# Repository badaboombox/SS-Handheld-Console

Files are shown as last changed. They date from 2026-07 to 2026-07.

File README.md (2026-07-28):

# SS Handheld Console

An open-source handheld game console built around an FPGA graphics engine. It runs
DS-era style 2D and 3D games at a steady 60 fps.

SS stands for Single Screen: a single-screen take on the dual-screen handheld era.

Most open-source consoles are 2D only, or run 3D in software that can't hold a
frame rate. This one does perspective-correct textured 3D and a GBA-class 2D
tile/sprite engine together on one FPGA, composited to a 480x272 panel
at 60 Hz. The whole bitstream builds with an open toolchain (Yosys, nextpnr,
Project Trellis), so no proprietary EDA is needed.

<p align="center">
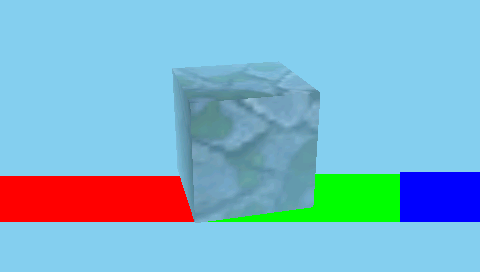
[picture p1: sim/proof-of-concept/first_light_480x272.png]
Textured, lit, fogged 3D from RTL sim
  
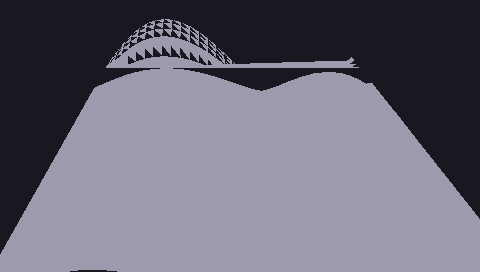
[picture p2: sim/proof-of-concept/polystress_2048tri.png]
2048-triangle stress scene at about 100 fps
  
</p>
<p align="center">
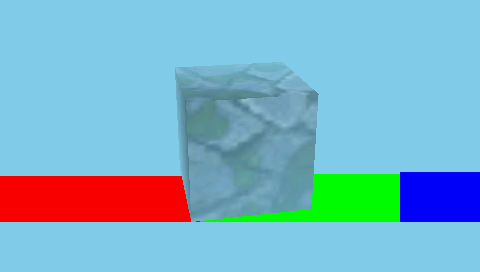
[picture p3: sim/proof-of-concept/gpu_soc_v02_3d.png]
Full SoC 3D render
  
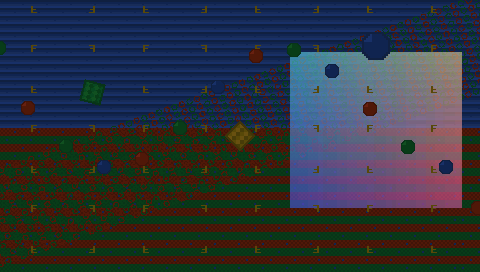
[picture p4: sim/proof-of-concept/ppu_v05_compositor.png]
Layered 2D with compositor
  
</p>

> These frames come straight out of the Verilog RTL in simulation. There are more
> in [sim/proof-of-concept/](sim/proof-of-concept/).

## What it is

Two chips split the work.

The Lattice ECP5 (LFE5U-85F) runs the graphics engine: a 2D tile and sprite PPU
(text and affine backgrounds, sprites, a scanline compositor), a perspective-correct
textured 3D rasterizer, a 32-bit SDRAM subsystem, and RGB panel scanout. All of it
is custom Verilog.

The STM32H723 runs game logic, audio, input, and 3D geometry, streaming
screen-space work to the FPGA over a parallel bus.

The 3D core is built on [RasterIX](https://github.com/ToNi3141/RasterIX) (see
[Credits](#credits)) and extended into a gaming-oriented hybrid GPU that sits next
to the 2D engine and compositor.

## Where it stands

Everything below is validated in simulation and synthesis.

- It fits the LFE5U-85F (caBGA-381) with room to spare: about 34% logic, 72% block
  RAM, 80% DSP.
- Both clock domains meet timing. The GPU domain runs at 73.5 MHz against a 66.67
  target, and the SDRAM domain at 174 MHz against a 133 target. The build is pinned
  to a deterministic place-and-route seed.
- The full pipeline is pixel-exact in simulation. The frames above are direct
  Verilator renders, including a 2048-triangle stress scene at roughly 100 fps.

## Repository layout

| Path | Contents |
|---|---|
| [rtl/](rtl/) | All the Verilog: 2D PPU, 3D integration, SDRAM controller and clock crossing, FMC bridge, scanout, clocking, board top. |
| [hardware/](hardware/) | KiCad project for the 6-layer board: ECP5, STM32H723, SDRAM, panel, power, audio, controls. |
| [build/](build/) | Bitstream build notes and the reproduce recipe. |
| [sim/](sim/) | Verilator testbenches for every RTL block plus a headless 3D harness. Rendered frames are in sim/proof-of-concept/. |

## Building the bitstream

No vendor tools:

```sh
yosys <synth script>            # produces gpuchip_ecp5.json
nextpnr-ecp5 --85k --package CABGA381 --speed 8 \
  --json gpuchip_ecp5.json --lpf rtl/gpu_chip.lpf --seed 4 \
  --textcfg gpuchip.config
ecppack gpuchip.config gpuchip.bit
```

The RTL depends on the RasterIX 3D core, included here as a submodule. Clone with
submodules so it comes along:

```sh
git clone --recursive <repo-url>
# or, in an existing clone:
git submodule update --init --recursive
```

The full recipe and flashing steps are in [build/README.md](build/README.md).

## Hardware

<p align="center">
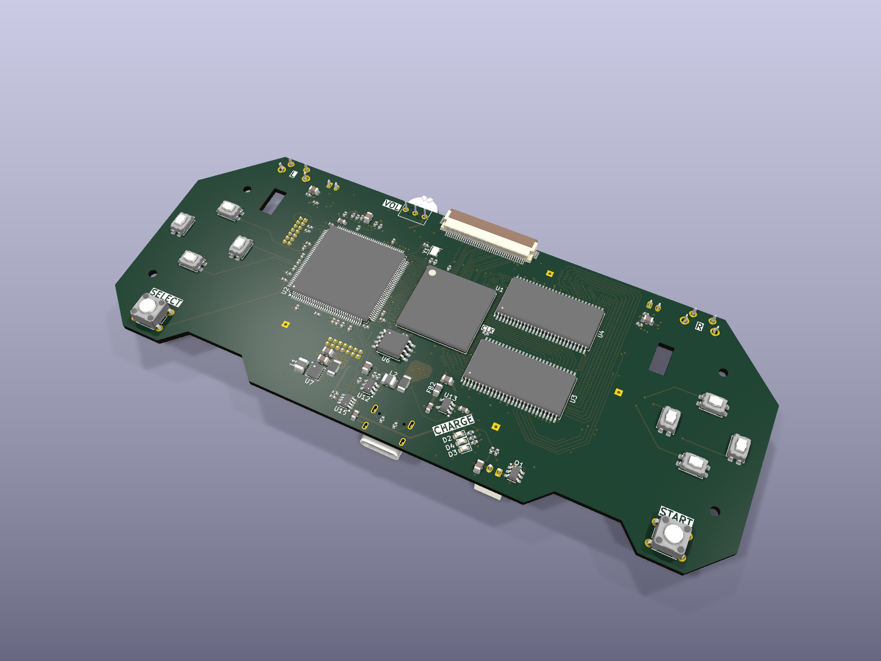
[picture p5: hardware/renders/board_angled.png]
3D render of the SS Handheld Console mainboard
  
</p>

A 6-layer board in KiCad: the ECP5-85 FPGA and STM32H723 MCU, 32-bit SDRAM, a 4.3
inch 480x272 RGB panel with a boost-driven backlight, microSD, USB-C charging,
stereo audio, and tactile controls. Schematics, layout, and 3D renders are under
[hardware/](hardware/).

## Status

This is a bring-up prototype (v0.1). The design is validated in simulation and
synthesis. First hardware bring-up and a likely v0.2 respin are the next steps.

## Credits

The 3D rasterizer is built on [RasterIX](https://github.com/ToNi3141/RasterIX) by
ToNi3141, an open-source fixed-function OpenGL-ES rasterizer (GPL-3.0). This
project extends it into a hybrid 2D and 3D console GPU. Big thanks to that work.

## License

The repository is dual-licensed by directory:

- rtl/ is GPL-3.0-or-later. The gateware is a derivative of RasterIX (GPL-3.0), so
  it carries the same copyleft terms.
- hardware/ is CERN-OHL-P-2.0, a permissive open-hardware license. The board is an
  independent work.

See [LICENSING.md](LICENSING.md) for the breakdown and the per-file SPDX tags.

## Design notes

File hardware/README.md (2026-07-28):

# Hardware

The KiCad project for the SS Handheld Console board. It's a 6-layer PCB that
carries the FPGA, the MCU, memory, the display interface, power, audio amps, and
controls (basically everything).

## Renders

<p align="center">
  Angled 3D render of the mainboard
</p>
<p align="center">
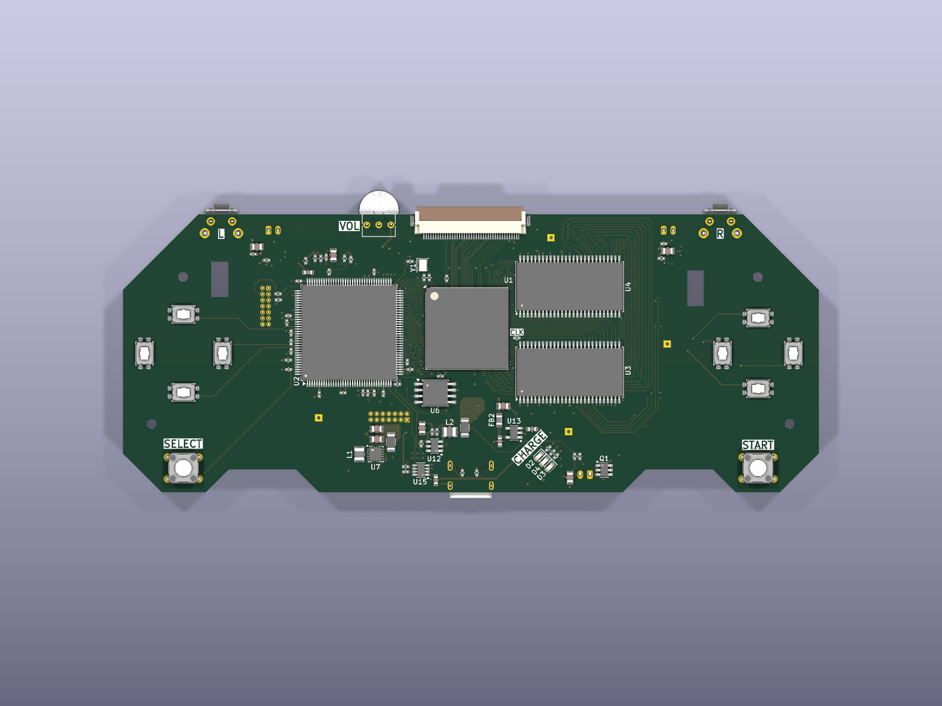
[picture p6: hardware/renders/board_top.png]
Top view
  
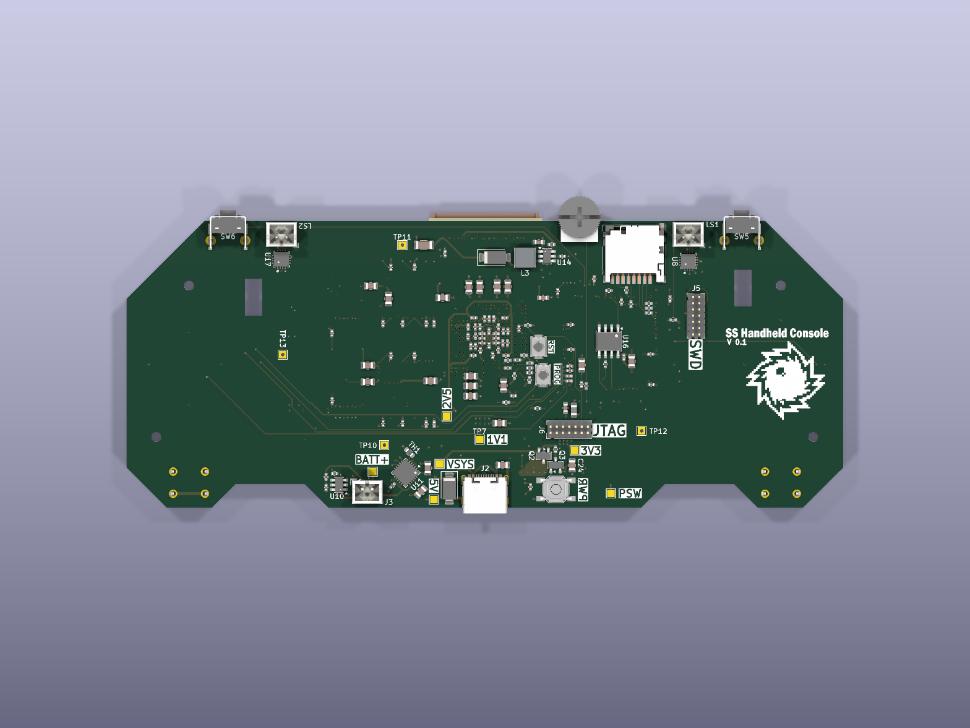
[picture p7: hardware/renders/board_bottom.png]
Bottom view
  
</p>

KiCad 3D renders of the current board (top, angled, and bottom).

## Main parts

- FPGA: Lattice ECP5 LFE5U-85F-8, caBGA-381, 0.8 mm pitch. Runs the main graphics engine.
- MCU: STM32H723, LQFP144. Game logic, audio, input, and some 3D geometry.
- Graphics memory: two 16-bit SDR SDRAM chips in parallel, for a 32-bit bus.
- Display: 4.3 inch 480x272 RGB (DPI) panel, with a boost-driven LED backlight.
- Storage: microSD, plus an SPI NOR flash that holds the FPGA configuration.
- MCU work RAM: QSPI PSRAM.
- Power: a single-cell 2500 mAh LiPo feeding a buck-boost 3.3 V rail, a 1.1 V core buck, a
  2.5 V aux LDO, and USB-C charging.
- Audio: stereo I2S class-D amplifiers.
- Controls: tactile D-pad, face, shoulder, and system buttons.

## Board

6-layer stackup: signal, ground, signal, ground, power, signal. The inner signal
layer sits between the two ground planes and mainly carries the SDRAM and FMC buses. The board uses
an ENIG finish for the fine-pitch BGA.

## Files

`Comp Board/` is the KiCad project: schematics, PCB, and the footprint and
3D-model libraries. Open `Comp Board/Comp Board.kicad_pro` in KiCad.

Exported for quick viewing without KiCad:

- [schematics.pdf](schematics.pdf) - all sheets.
- [board_layout.pdf](board_layout.pdf) - all six copper layers, one per page.
- [BOM.csv](BOM.csv) - grouped bill of materials (76 line items).

## License

The hardware is licensed under CERN-OHL-P-2.0 (see the LICENSE file in this
directory). The RTL under `rtl/` is licensed separately, under GPL-3.0-or-later.

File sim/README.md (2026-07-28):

# Simulation

Verilator testbenches for each RTL block, plus a headless harness for the 3D core.
The frames these produce are in [proof-of-concept/](proof-of-concept/).

| Directory | What it tests |
|---|---|
| ppu/ | 2D PPU: tile and affine backgrounds, sprites, compositor. Renders a frame to `ppu_frame.ppm`. |
| ppu_sdram/ | The PPU running over the real SDRAM controller and cache. |
| gpu/ | The full graphics SoC top (PPU, 3D, SDRAM, FMC bridge). |
| sdram/ | The SDR SDRAM controller: init, refresh, burst-8. |
| fmc/ | The STM32 FMC parallel-bus bridge. |
| scanout/ | The DPI/RGB panel timing generator. |
| headless/ | The 3D core harness (CMake). Needs the RasterIX submodule. |

Each Verilator directory builds and runs with `make`. The headless harness uses
CMake and needs `external/RasterIX` (see the top-level README for the submodule
command).

Requirements: Verilator 5.x, and for the headless harness, CMake plus the RasterIX
submodule.

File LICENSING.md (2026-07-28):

# Licensing

This project is dual-licensed by directory, because the gateware and the hardware
have different origins and obligations.

## rtl/ is GPL-3.0-or-later

The RTL is a derivative work of [RasterIX](https://github.com/ToNi3141/RasterIX),
which is licensed GPL-3.0. Strong copyleft propagates: any distributed work that
incorporates GPL-3.0 code must itself be GPL-3.0-compatible. So all the Verilog
under rtl/ is licensed GPL-3.0-or-later. The full text is in [LICENSE](LICENSE).

`SPDX-License-Identifier: GPL-3.0-or-later`

## hardware/ is CERN-OHL-P-2.0

The PCB and KiCad design under hardware/ is an independent work. It hosts the FPGA;
it is not a derivative of the GPL RTL. It is licensed under the CERN Open Hardware
Licence Version 2, Permissive (CERN-OHL-P-2.0), so the board can be used, modified,
and manufactured freely. The full text is in [hardware/LICENSE](hardware/LICENSE).

`SPDX-License-Identifier: CERN-OHL-P-2.0`

## Media

Render frames and documentation images (sim/proof-of-concept/ and the README
images) are licensed CC-BY-4.0.

`SPDX-License-Identifier: CC-BY-4.0`

## Third party

RasterIX (external/RasterIX, pulled in as a submodule) is copyright ToNi3141 and
licensed GPL-3.0. It is not redistributed in this repository. See its own
repository for its license and terms.

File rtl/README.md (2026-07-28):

# RTL

All the Verilog for the SS Handheld graphics engine. It targets a Lattice
ECP5 (LFE5U-85F) and builds with Yosys and nextpnr.

## Top level

- `gpu_chip.v` is the board and synthesis top. It wraps the SoC, brings out the
  real chip pins (SDRAM, FMC, panel, clock, reset), sets up the PLL, and forwards
  the SDRAM clock through an ODDR. This is what gets synthesized into a bitstream.
- `gpu_top.v` is the SoC. It ties together the 2D PPU, the 3D core, the SDRAM
  subsystem, and the FMC bridge, along with the SDRAM arbitration and the
  framebuffer swap logic.
- `gpu_chip.lpf` holds the pin constraints (ball assignments and IO standards) for
  the CABGA381 package.
- `clkgen.v` sets up the ECP5 PLL: one 50 MHz reference in, a 66.67 MHz GPU clock
  and a 133.33 MHz SDRAM clock out.

## Blocks

| Path | What it does |
|---|---|
| ppu/ | 2D tile and sprite PPU: text and affine backgrounds, sprites, a shared cache and arbiter, and a scanline compositor. See [ppu/PPU_Microarch.md](ppu/PPU_Microarch.md). |
| sdram/ | 32-bit SDR SDRAM controller (init, refresh, burst-8), an AXI bridge, and the clock crossing that puts the controller in its own 133 MHz domain. |
| fmc/ | The STM32 FMC parallel-bus slave and the register file it drives. |
| scanout/ | DPI/RGB panel timing generator (480x272, sync and DE, RGB888 out). |

The 3D rasterizer is RasterIX, pulled in as a submodule at `external/RasterIX`, so
it is not part of this directory. `gpu_top` instantiates it.

## Clock domains

- GPU domain (66.67 MHz): the PPU, the 3D core, compositing, and scanout.
- SDRAM domain (133.33 MHz, exactly twice the GPU clock): the SDRAM controller,
  reached from the GPU domain through async FIFOs.

## Building

See the top-level README and [../build/README.md](../build/README.md). In short,
Yosys synthesizes `gpu_chip`, nextpnr places and routes it against `gpu_chip.lpf`,
and ecppack makes the bitstream. The build is pinned to a place-and-route seed so
timing is repeatable.

## Style

The RTL is written to synthesize cleanly with Yosys: Verilog-2005, memories as
plain arrays, no empty for-loop increments, and simulation-only asserts guarded by
`ifdef SIMULATION`.

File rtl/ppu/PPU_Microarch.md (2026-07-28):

# 2D PPU (Pixel Processing Unit) microarchitecture

The PPU renders one scanline at a time into a line buffer, which the scanout block
then streams to the panel. It draws four background layers (text or affine) and
sprites, composites them by priority with alpha blending, and can mix in the 3D
color buffer as another layer.

## Pipeline

All the renderers run concurrently for a given line. They share a single memory
port through a fixed-priority arbiter and a shared cache, so the per-line cost is
bounded by memory instead of the number of layers.

- The background renderers (text and affine) each produce one layer's pixels for
  the line.
- The sprite renderer scans the OAM for sprites on this line and plots them into
  a sprite line buffer.
- The 3D fetch unit reads the 3D color buffer for the line. It bypasses the cache,
  since that buffer is written once per frame and would only take up cache space.
- The compositor resolves all the sources by priority, applies alpha blending and
  brightness, and writes the final RGB565 pixel.

At 66.67 MHz the worst-case scene renders in about 35 microseconds per line, inside
the roughly 56 microsecond line budget. The shared cache runs around an 83% hit
rate on that scene.

## Backgrounds

- Text layers: 64x64 tilemaps of 8x8 4bpp tiles, 16 palettes, fine x and y scroll,
  horizontal and vertical flip.
- Affine layers: layers 2 and 3 can switch to affine mode. A DDA walks an s8.8
  matrix across a 512x512 wrapping world, with small map and tile caches.

## Sprites

- 256-entry OAM, preloaded over a write port.
- A per-line scan collects up to 64 sprites on the line.
- Square sizes from 8 to 64, 1D tile mapping, horizontal and vertical flip.
- X wraps in a 1024-wide space, so sprites clip cleanly off either edge.
- First writer wins per pixel, in OAM order, and a sprite beats a background at
  equal priority.
- Affine sprites use a 32-entry matrix table and GBA-style inverse mapping, with an
  optional double-size window.

## Compositor

- Per-pixel priority resolve across the four backgrounds, the sprite layer, and the
  3D layer.
- Alpha blending with a global eva and evb pair (in sixteenths) and a per-source
  enable.
- Brightness fade.
- The 3D color buffer is treated as a priority-assignable layer, so the compositor
  does not care about the ratio of 2D to 3D content.

## Formats

- Tilemap entry (16 bits): bits 9:0 tile index, bit 10 hflip, bit 11 vflip, bits
  15:12 palette.
- Tile: 8 rows of 32 bits, one 4bpp pixel per nibble, left pixel in the low nibble
  before flipping.
- Color 0 of each palette is transparent.
- Line-buffer color is RGB565.

## Files

| File | Role |
|---|---|
| ppu_top.v | Line sequencer and top level. |
| ppu_bg_line.v | Text background scanline renderer. |
| ppu_bg_affine_line.v | Affine background scanline renderer. |
| ppu_spr_line.v | Sprite scanline renderer: OAM scan, plotting, affine sprites. |
| ppu_arbiter.v | Fixed-priority memory arbiter. |
| ppu_cache.v | Shared direct-mapped read cache, flushed at frame start. |
| ppu_t3d_fetch.v | 3D color-buffer line fetch (bypasses the cache). |
| ppu_sdram_top.v | PPU wired to the SDRAM controller, for integration and sim. |

## Style

The RTL is Verilog-2005 and synthesizes cleanly with Yosys: memories are plain
arrays, there are no empty for-loop increments, and simulation asserts are guarded
by `ifdef SIMULATION`.

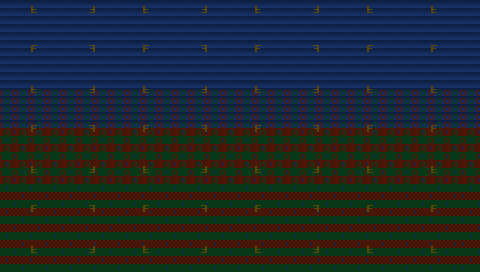
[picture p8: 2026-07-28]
sim/proof-of-concept/ppu_v02_4layers.png

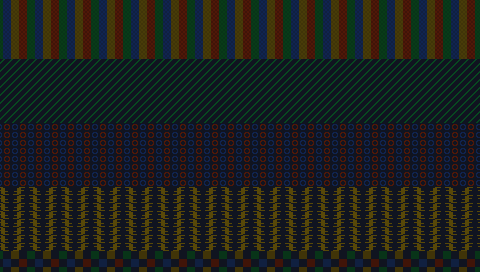
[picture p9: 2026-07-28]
sim/proof-of-concept/ppu_v01_first_frame.png

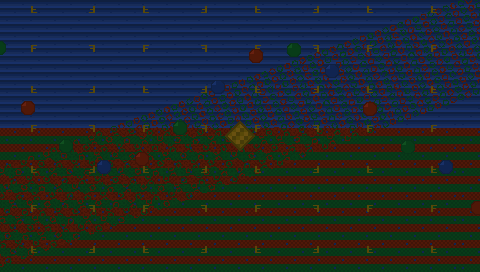
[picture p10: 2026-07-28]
sim/proof-of-concept/ppu_v04_affine.png

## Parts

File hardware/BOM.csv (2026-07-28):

Item | Designators | Value | Footprint | Qty | DNP
1 | C1,C3-C5,C19,C24,C27,C44,C51,C54,C61-C64,C88,C99,C103,C107,C111,C112,C119,C120,C130 | 10uF | Capacitor_SMD:C_0805_2012Metric | 23
2 | C2,C6-C18,C20,C31-C43,C45,C47,C52,C53,C55-C60,C65-C72,C74-C77,C85,C86,C89,C90,C92-C94,C96-C98,C100,C104,C105,C108,C110,C113-C118,C121-C126,C129,C131-C134 | 100nF | Capacitor_SMD:C_0402_1005Metric | 82
3 | C21,C28,C48 | 1uF | Capacitor_SMD:C_0603_1608Metric | 3
4 | C22 | 0.47uF | Capacitor_SMD:C_0402_1005Metric | 1
5 | C23 | 47nF | Capacitor_SMD:C_0402_1005Metric | 1
6 | C25,C26,C46,C87,C91,C95 | 22uF | Capacitor_SMD:C_0805_2012Metric | 6
7 | C29,C49,C50 | 2.2uF | Capacitor_SMD:C_0603_1608Metric | 3
8 | C30 | 4.7uF | Capacitor_SMD:C_0603_1608Metric | 1
9 | C127 | 1uF | Capacitor_SMD:C_1206_3216Metric | 1
10 | C128 | 220nF | Capacitor_SMD:C_0402_1005Metric | 1
11 | D1 | SMAJ5.0A | Diode_SMD:D_SMA | 1
12 | D2-D4 | LED | LED_SMD:LED_0603_1608Metric | 3
13 | D5 | SS16 | Diode_SMD:D_SMA | 1
14 | FB1 | 600@100MHz | Inductor_SMD:L_0805_2012Metric | 1
15 | FB2 | 120@100MHz | Inductor_SMD:L_0805_2012Metric | 1
16 | J1 | Micro_SD_Card_Det1 | Connector_Card:microSD_HC_Hirose_DM3D-SF | 1
17 | J2 | USB_C_Receptacle_USB2.0_16P | Connector_USB:USB_C_Receptacle_G-Switch_GT-USB-7010ASV | 1
18 | J3 | 1S LiPo | Connector_JST:JST_PH_B2B-PH-K_1x02_P2.00mm_Vertical | 1
19 | J4 | 0.5mm FPC Conn | Connector_FFC-FPC:Hirose_FH12-40S-0.5SH_1x40-1MP_P0.50mm_Horizontal | 1
20 | J5,J6 | Conn_ST_STDC14 | Connector_PinHeader_1.27mm:PinHeader_2x07_P1.27mm_Vertical | 2
21 | L1 | 1.5uH | Inductor_SMD:L_1008_2520Metric | 1
22 | L2 | 2.2uH | Inductor_SMD:L_1008_2520Metric | 1
23 | L3 | 10uH | Inductor_SMD:L_Abracon_ASPI-4030S | 1
24 | LS1,LS2 | Speaker 4-8 ohm | Connector_TE-Connectivity:TE_440054-2_1x02_P2.00mm_Vertical | 2
25 | Q1 | FS8205 | Package_TO_SOT_SMD:SOT-23-6 | 1
26 | Q2 | AO3401A | Package_TO_SOT_SMD:SOT-23 | 1
27 | Q3 | 2N7002 | Package_TO_SOT_SMD:SOT-23 | 1
28 | R1,R2 | 5.1k | Resistor_SMD:R_0402_1005Metric | 2
29 | R3,R8 | 2k | Resistor_SMD:R_0402_1005Metric | 2
30 | R4,R9,R41 | 1k | Resistor_SMD:R_0402_1005Metric | 3
31 | R5-R7 | 470 | Resistor_SMD:R_0402_1005Metric | 3
32 | R10,R45-R49 | 47k | Resistor_SMD:R_0402_1005Metric | 6
33 | R11-R13,R15,R53 | 100k | Resistor_SMD:R_0402_1005Metric | 5
34 | R14 | 120k | Resistor_SMD:R_0402_1005Metric | 1
35 | R16,R19-R22,R33-R36,R42,R43,R57 | 10k | Resistor_SMD:R_0402_1005Metric | 12
36 | R17,R18 | 49.9 | Resistor_SMD:R_0402_1005Metric | 2
37 | R23-R28,R44,R56 | 22 | Resistor_SMD:R_0402_1005Metric | 8
38 | R29,R38,R55 | 33 | Resistor_SMD:R_0402_1005Metric | 3
39 | R30-R32,R40 | 4.7k | Resistor_SMD:R_0402_1005Metric | 4
40 | R37 | 10 | Resistor_SMD:R_0402_1005Metric | 1
41 | R39 | 240k | Resistor_SMD:R_0402_1005Metric | 1
42 | R50,R51 | 0 | Resistor_SMD:R_1206_3216Metric | 2
43 | R54 | 220k | Resistor_SMD:R_0402_1005Metric | 1
44 | RV1 | 10k Linear | Potentiometer_THT:Potentiometer_Bourns_3266Y_Vertical | 1
45 | SW1 | D_UP | Button_Switch_SMD:SW_SPST_EVQP2_ShortPushTravel_H2.5mm | 1
46 | SW2 | D_DOWN | Button_Switch_SMD:SW_SPST_EVQP2_ShortPushTravel_H2.5mm | 1
47 | SW3 | D_LEFT | Button_Switch_SMD:SW_SPST_EVQP2_ShortPushTravel_H2.5mm | 1
48 | SW4 | D_RIGHT | Button_Switch_SMD:SW_SPST_EVQP2_ShortPushTravel_H2.5mm | 1
49 | SW5 | L | Button_Switch_THT:SW_Tactile_SPST_Angled_PTS645Vx39-2LFS | 1
50 | SW6 | R | Button_Switch_THT:SW_Tactile_SPST_Angled_PTS645Vx39-2LFS | 1
51 | SW7 | A | Button_Switch_SMD:SW_SPST_EVQP2_ShortPushTravel_H2.5mm | 1
52 | SW8 | B | Button_Switch_SMD:SW_SPST_EVQP2_ShortPushTravel_H2.5mm | 1
53 | SW9 | X | Button_Switch_SMD:SW_SPST_EVQP2_ShortPushTravel_H2.5mm | 1
54 | SW10 | Y | Button_Switch_SMD:SW_SPST_EVQP2_ShortPushTravel_H2.5mm | 1
55 | SW11 | START | Button_Switch_THT:SW_TH_Tactile_Omron_B3F-100x | 1
56 | SW12 | SEL | Button_Switch_THT:SW_TH_Tactile_Omron_B3F-100x | 1
57 | SW13 | MAIN | Button_Switch_SMD:SW_SPST_SKQG_WithStem | 1
58 | SW14 | FORCE_RECON | Button_Switch_SMD:SW_Push_SPST_NO_Alps_SKRK | 1
59 | SW15 | SW_Push | Button_Switch_SMD:SW_Push_SPST_NO_Alps_SKRK | 1
60 | TH1 | NTC 10k | Resistor_SMD:R_0603_1608Metric | 1
61 | TP1,TP3-TP5,TP7-TP9 | TestPoint | TestPoint:TestPoint_Pad_1.5x1.5mm | 7
62 | TP10-TP13 | TestPoint | TestPoint:TestPoint_THTPad_1.5x1.5mm_Drill0.7mm | 4
63 | U1 | LFE5U-85F-8BG381x | Package_BGA:Lattice_caBGA-381_17x17mm_Layout20x20_P0.8mm | 1
64 | U2 | STM32H723ZGTx | Package_QFP:LQFP-144_20x20mm_P0.5mm | 1
65 | U3,U4 | AS4C4M16SA | Package_SO:TSOP-II-54_22.2x10.16mm_P0.8mm | 2
66 | U6 | W25Q32JVSS | Package_SO:SOIC-8_5.3x5.3mm_P1.27mm | 1
67 | U7 | TPS63001 | Package_SON:Texas_DRC0010J_ThermalVias | 1
68 | U8,U17 | MAX98357A | Package_DFN_QFN:TQFN-16-1EP_3x3mm_P0.5mm_EP1.23x1.23mm | 2
69 | U10 | DW01A | Package_TO_SOT_SMD:SOT-23-6 | 1
70 | U11 | MCP73871 | Package_DFN_QFN:QFN-20-1EP_4x4mm_P0.5mm_EP2.5x2.5mm | 1
71 | U12 | TLV62569DDC | Package_TO_SOT_SMD:SOT-23-6 | 1
72 | U13 | AP2112K-2.5 | Package_TO_SOT_SMD:SOT-23-5 | 1
73 | U14 | TPS61165DBV | Package_TO_SOT_SMD:SOT-23-6 | 1
74 | U15 | LTC2954CTS8-1-TRPBF | Package_TO_SOT_SMD:TSOT-23-8 | 1
75 | U16 | APS6404L-3SQRx-SN | Package_SO:SOIC-8_3.9x4.9mm_P1.27mm | 1
76 | Y1 | SiT8008xx-7x-xxE | Oscillator:Oscillator_SMD_SiT_PQFN-4Pin_2.0x1.6mm | 1

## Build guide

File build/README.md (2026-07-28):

# Board-top bitstream

The ready-to-flash FPGA configuration for the board top (`gpu_chip`), built at a
pinned place-and-route seed. This is NOT a final build, so you should
rebuild it after any RTL change. A few things are still unfinished (command
response readback, NWAIT polarity, and real SDRAM pad timing).

The `.bit` and `.svf` binaries are git-ignored and regenerable. This README and the
verilog itself are tracked.

## Artifacts

- `gpuchip.bit` (about 2.3 MB): the SPI-flash image for the W25Q32 config flash,
  which the ECP5 boots from on power-up.
- `gpuchip.svf` (about 4.8 MB): a JTAG program file for a direct volatile load
  during bring-up.

## Provenance

- RTL: `rtl/gpu_chip.v` (the board top, with an ODDR-driven SDRAM clock), the rest
  of `rtl/`, and the RasterIX submodule.
- Pinout: `rtl/gpu_chip.lpf` (LFE5U-85F, CABGA381, 117 IO). nextpnr places all 117
  with no conflicts.
- Tools: Yosys, nextpnr-ecp5, and ecppack from Project Trellis.
- The build is pinned to a place-and-route seed because the GPU clock is
  seed-sensitive. The pinned seed gives clean margin and is deterministic.
- Post-route timing: GPU clock 73.46 MHz against a 66.67 target, SDRAM clock
  174.58 MHz against a 133.33 target, so both pass.

## Regenerate

```sh
yosys gpuchip.ys                 # creates gpuchip_ecp5.json
nextpnr-ecp5 --85k --package CABGA381 --speed 8 \
  --json gpuchip_ecp5.json --lpf ../rtl/gpu_chip.lpf --lpf-allow-unconstrained \
  --seed 4 --textcfg gpuchip.config
ecppack gpuchip.config gpuchip.bit         # SPI-flash image
ecppack --svf gpuchip.svf gpuchip.config   # JTAG
```

## Flashing at bring-up

- SPI flash: write `gpuchip.bit` to the W25Q32, for example with
  `openFPGALoader -c <cable> -f gpuchip.bit`, or through the config-flash header.
  The ECP5 boots it during power on, with the config straps set to Master SPI.
- JTAG bench load: `openFPGALoader -c <cable> gpuchip.svf` for a quick volatile
  load without touching flash.

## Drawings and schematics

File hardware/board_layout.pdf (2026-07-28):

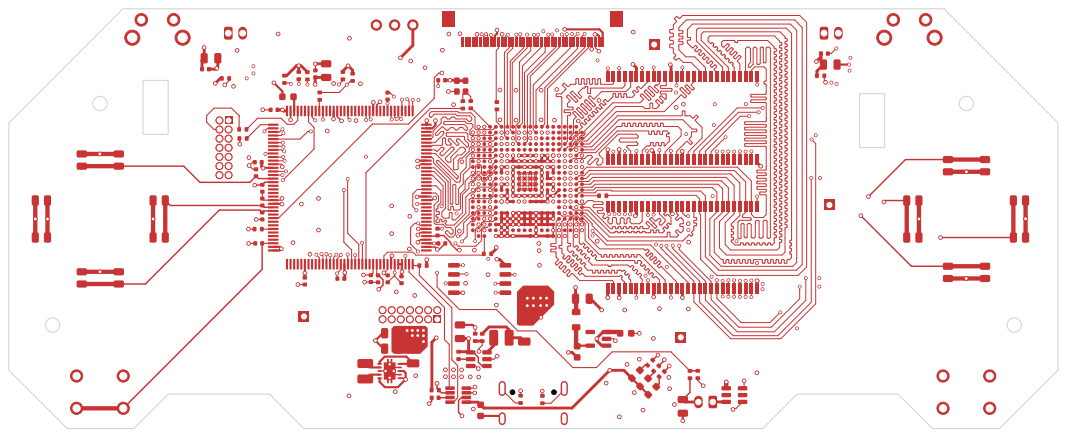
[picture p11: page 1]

Size: A4 | Rev:
KiCad E.D.A. 10.0.3 | Id: 1/6

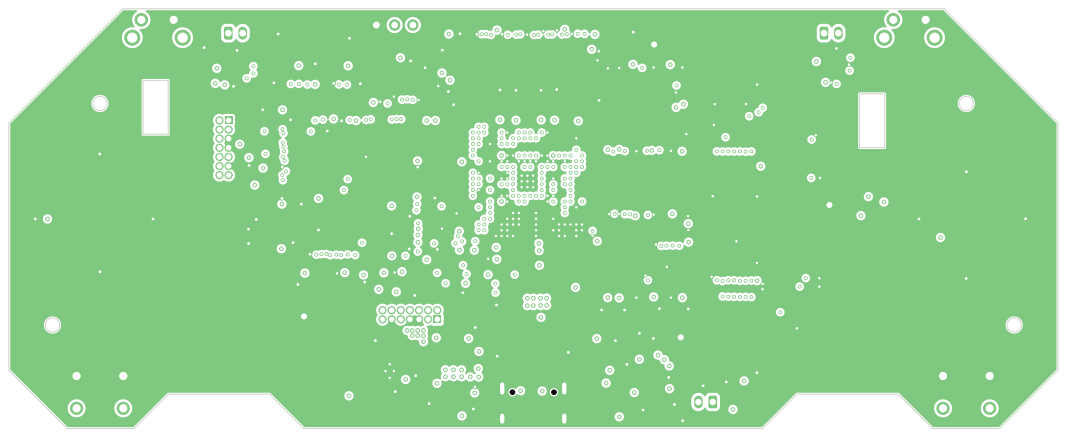
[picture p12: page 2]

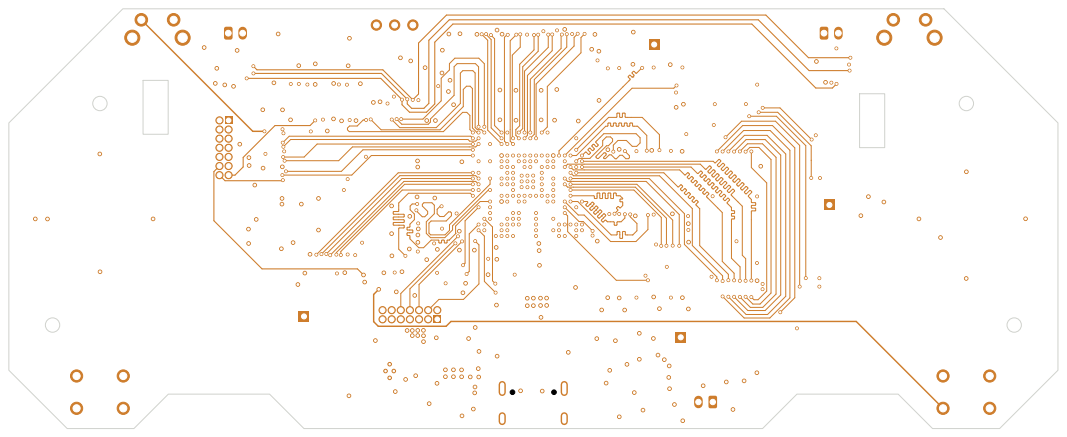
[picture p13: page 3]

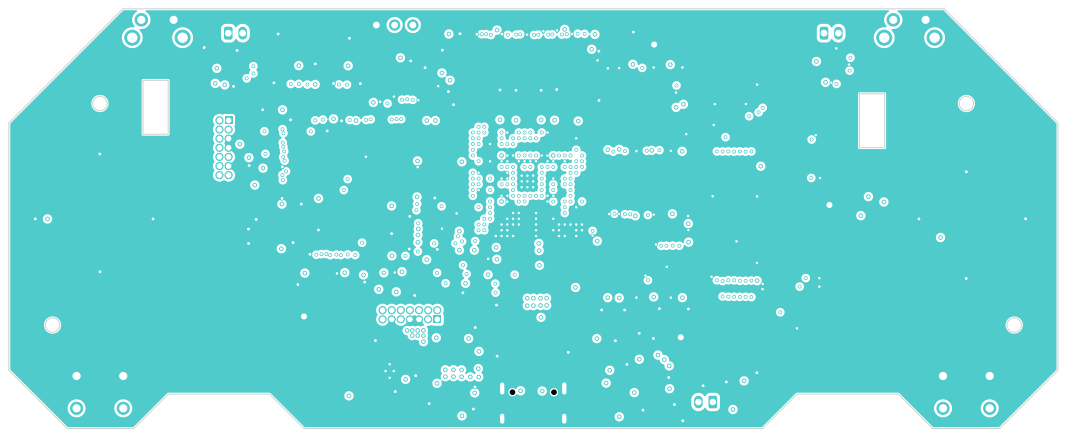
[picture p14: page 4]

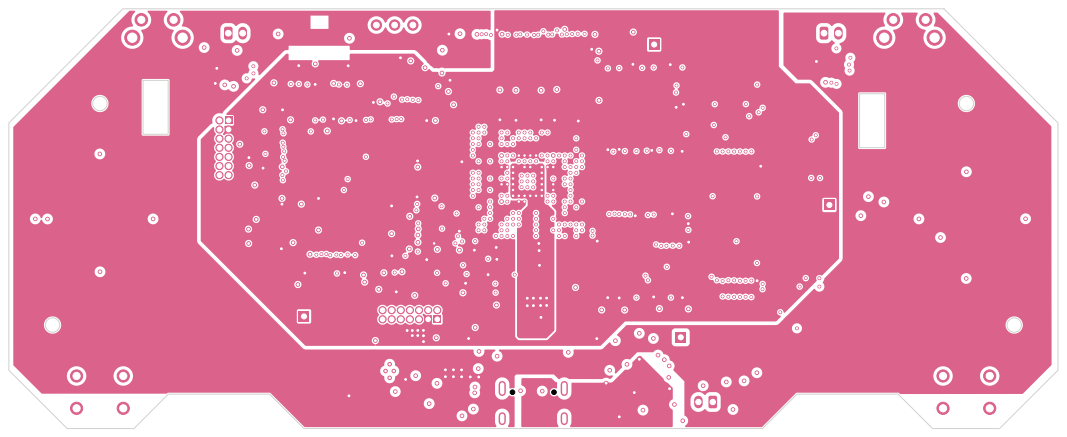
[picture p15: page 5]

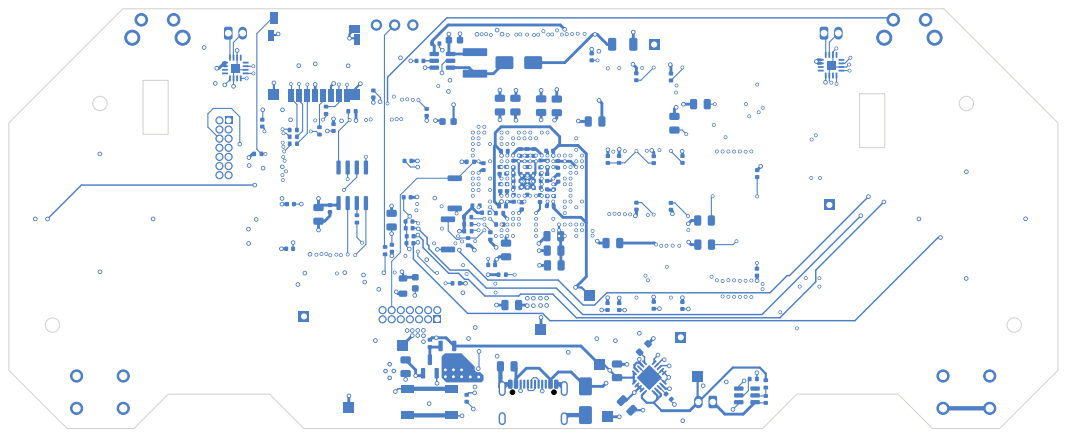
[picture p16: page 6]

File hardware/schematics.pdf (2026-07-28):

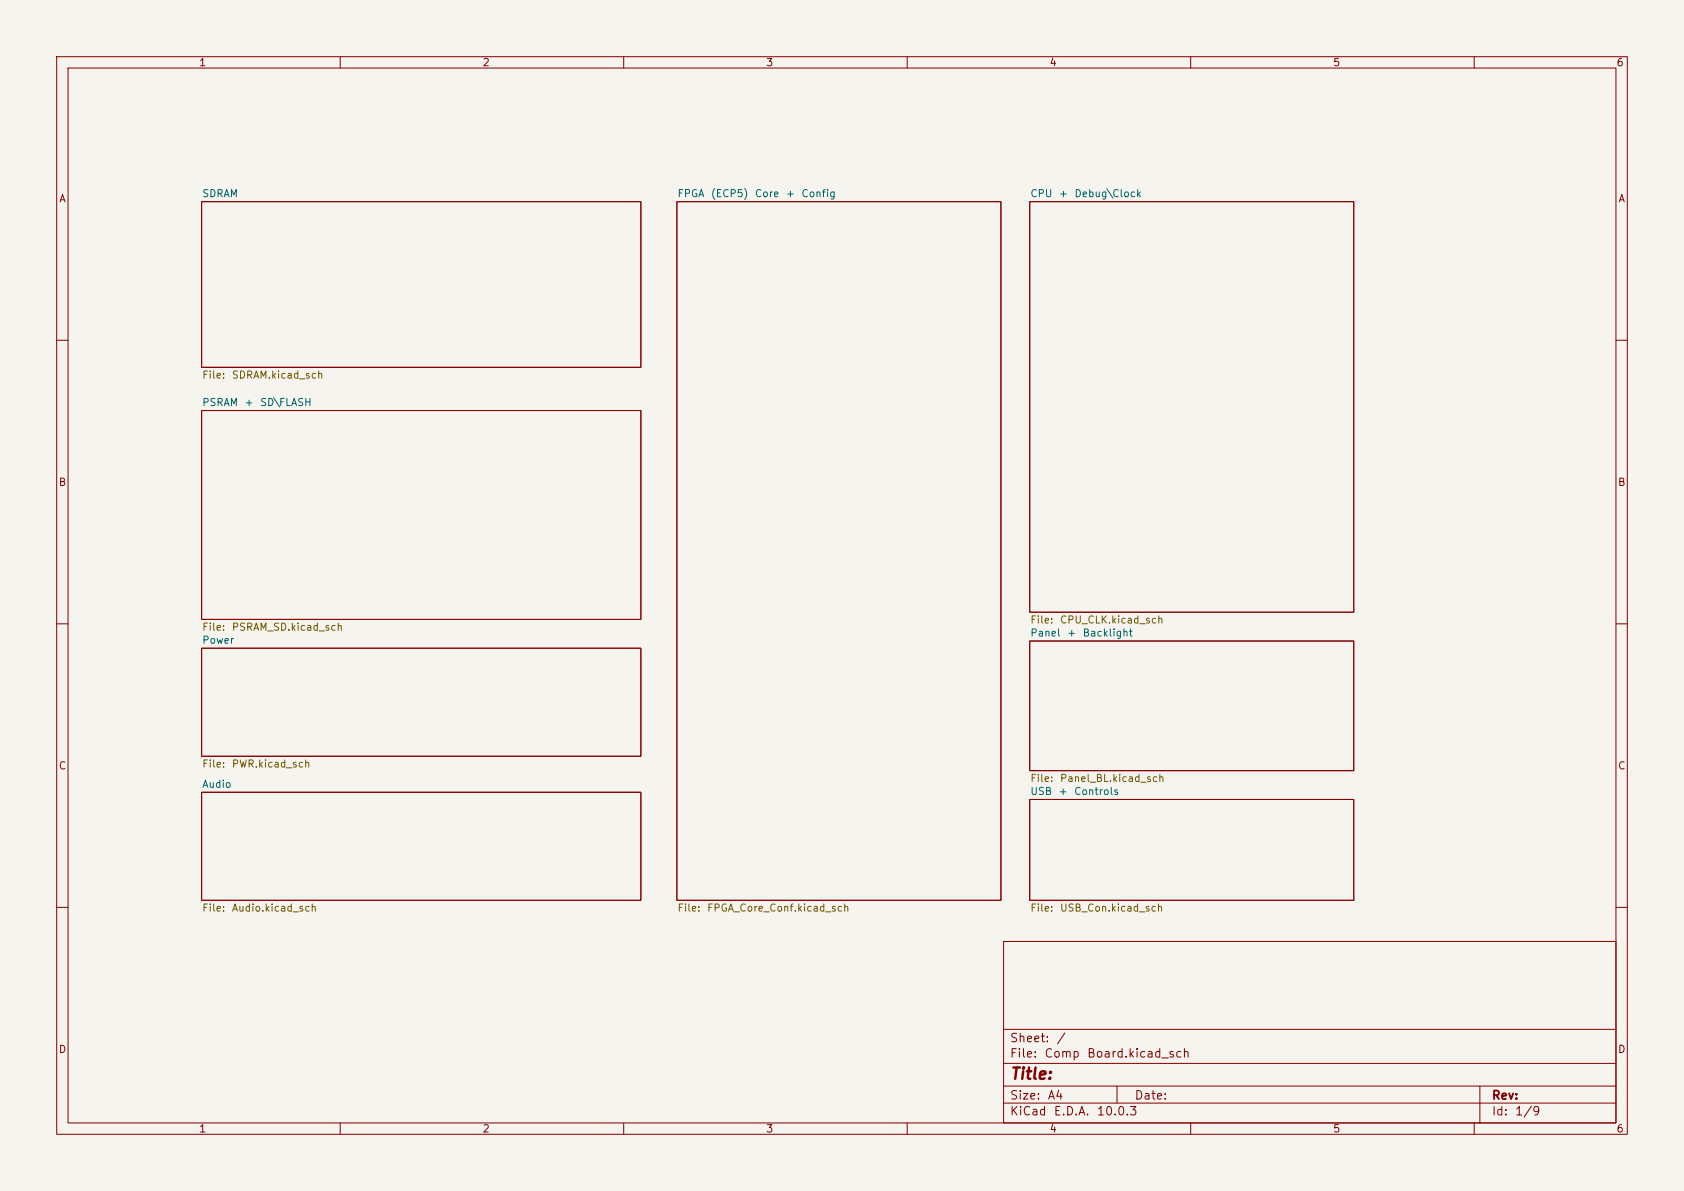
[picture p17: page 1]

CPU + Debug\Clock File: CPU_CLK.kicad_sch PSRAM + SD\FLASH

Size: A4 | Rev:
KiCad E.D.A. 10.0.3 | Id: 1/9

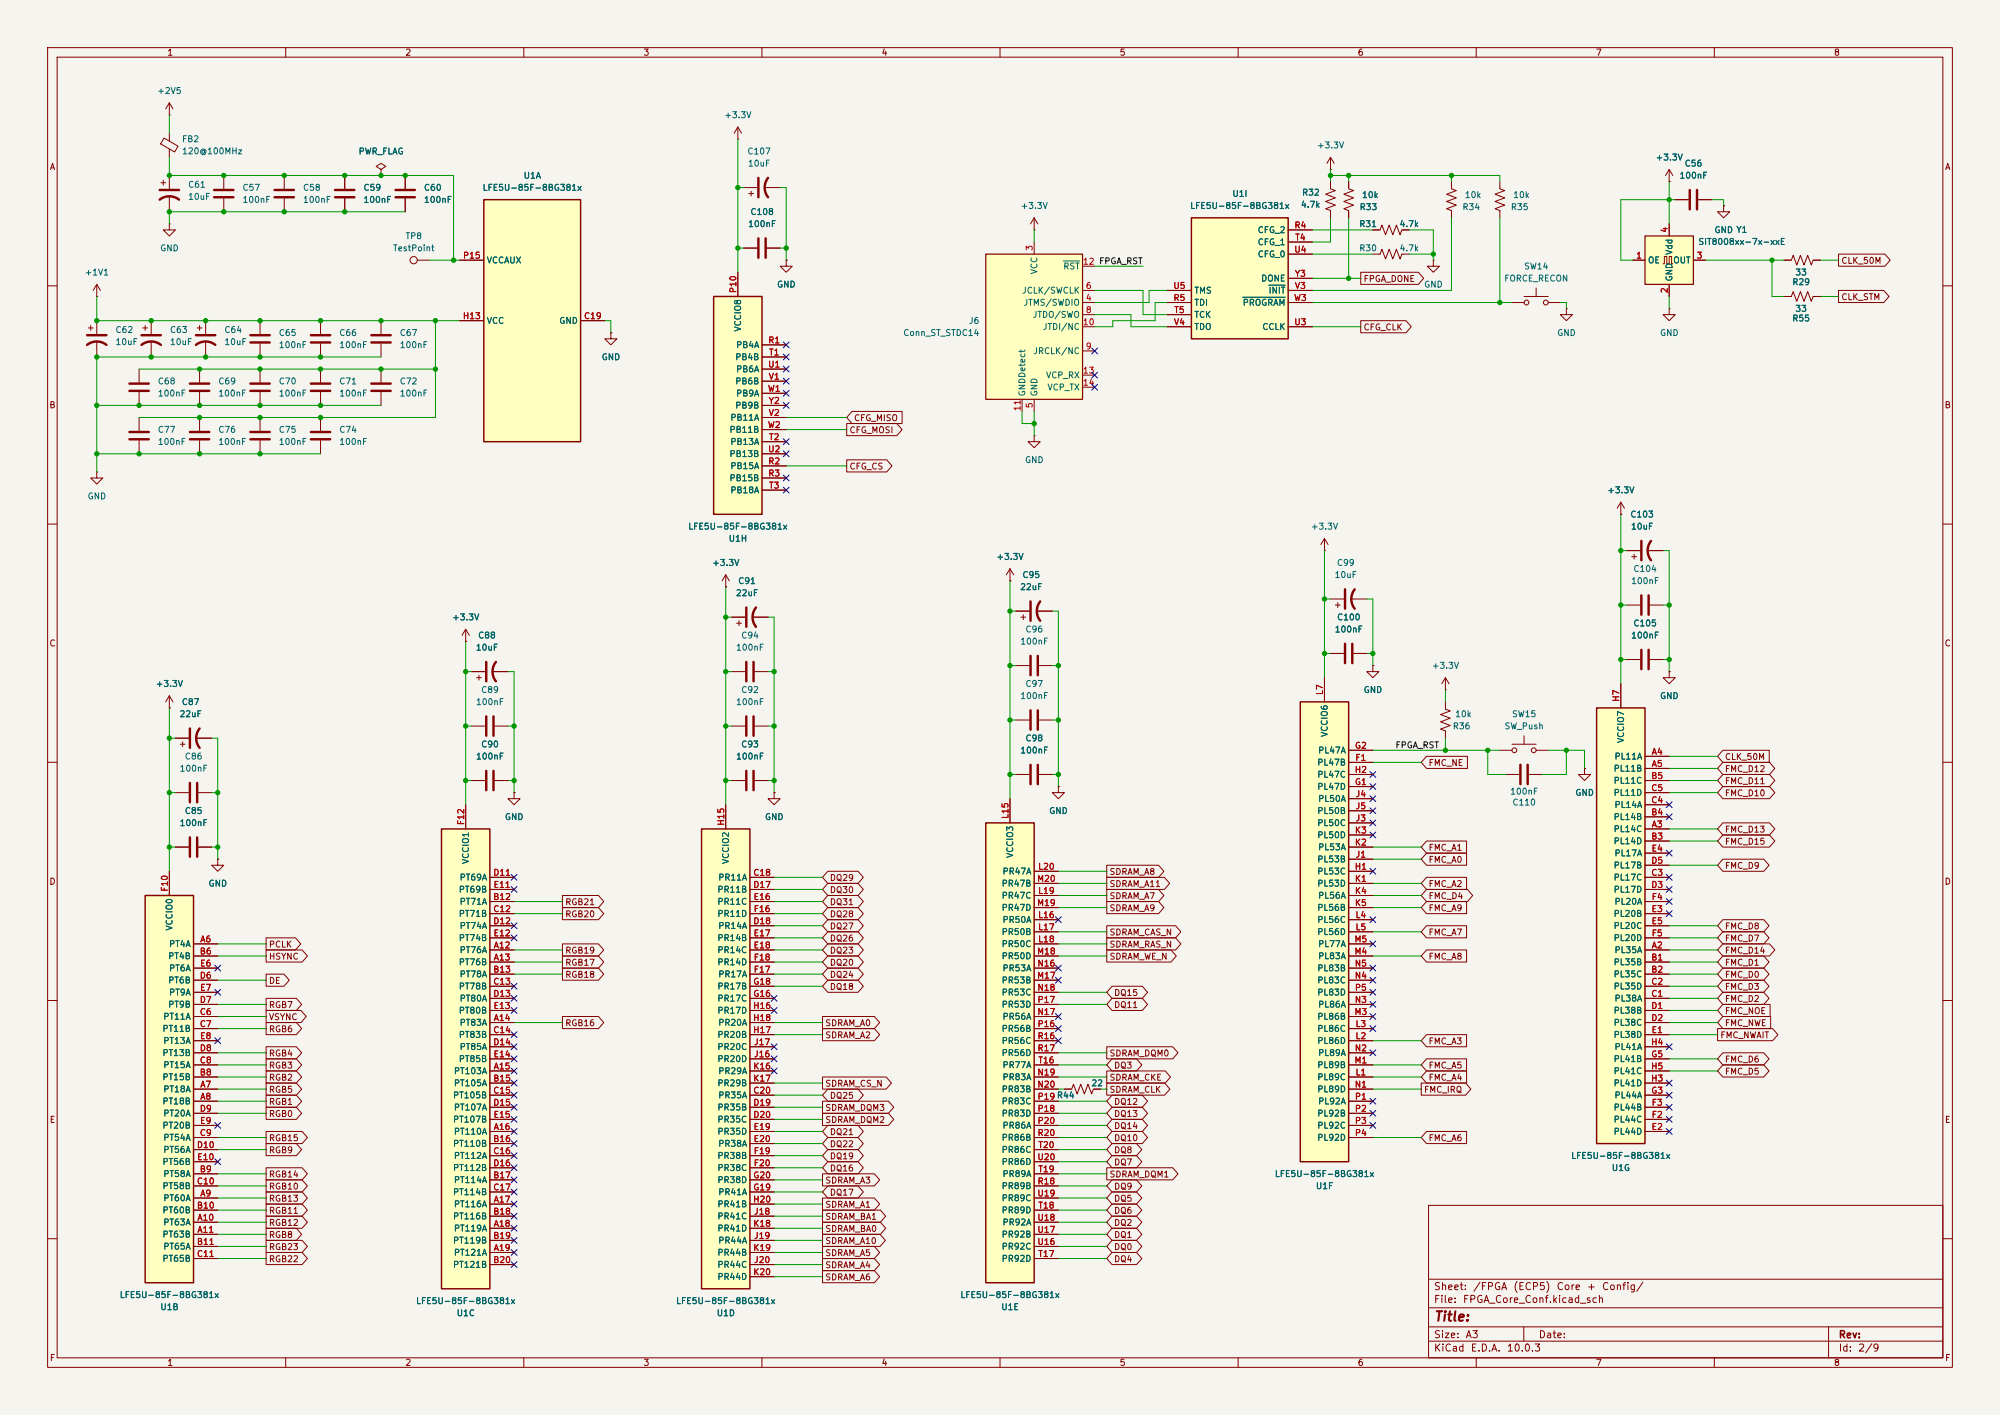
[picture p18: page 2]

Sheet: /FPGA (ECP5) Core + Config/
File: FPGA_Core_Conf.kicad_sch
Title:

Size: A3 | Rev:

F Date:

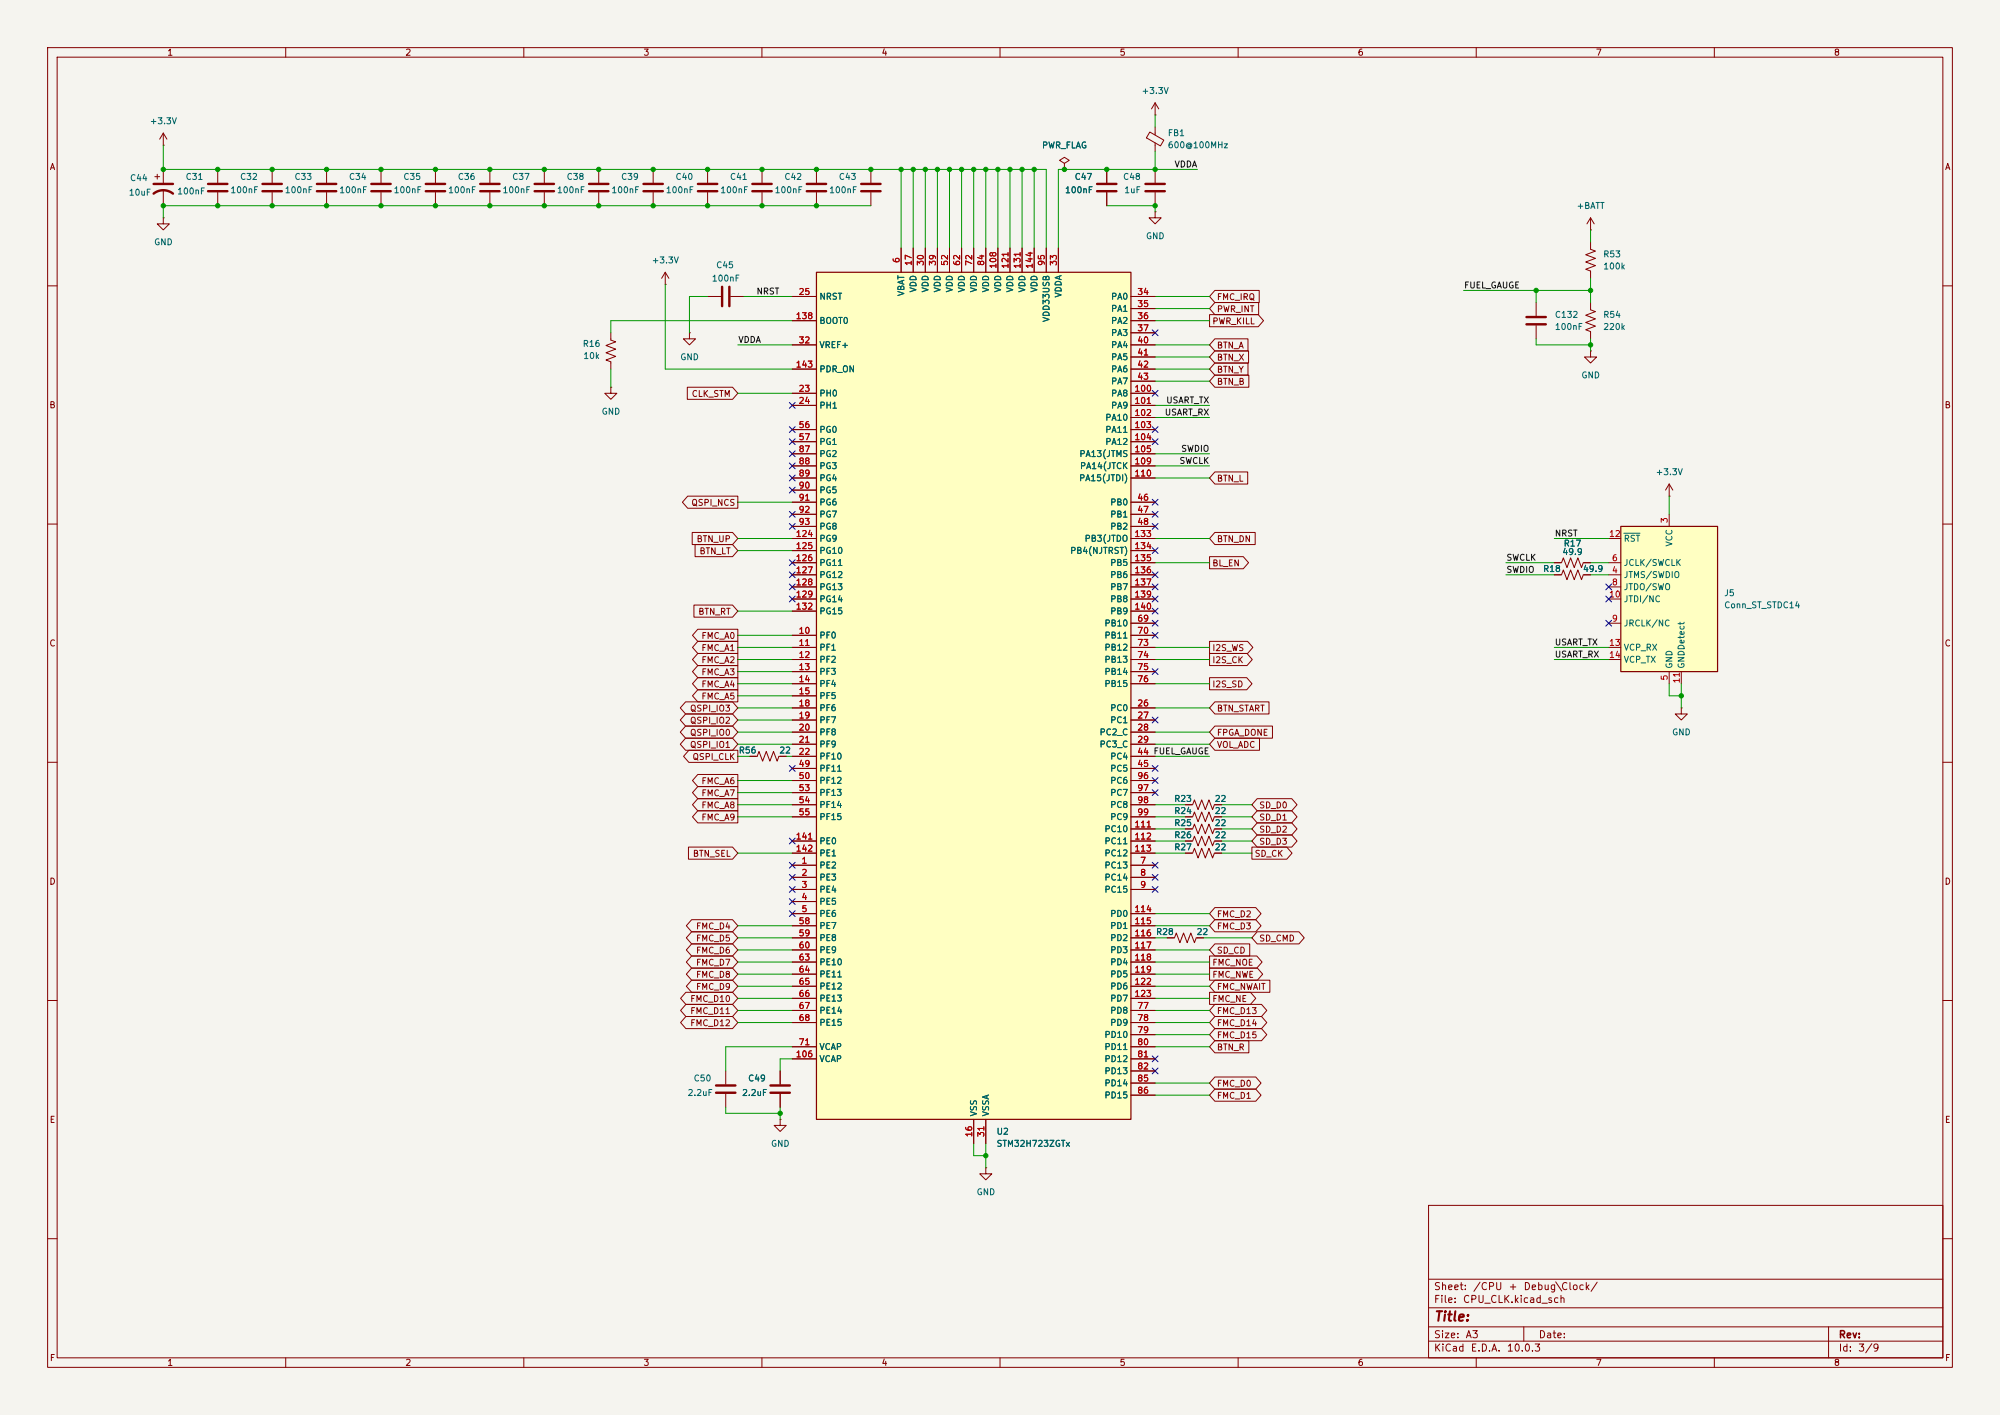
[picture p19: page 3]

Sheet: /CPU + Debug\Clock/
File: CPU_CLK.kicad_sch
Title:

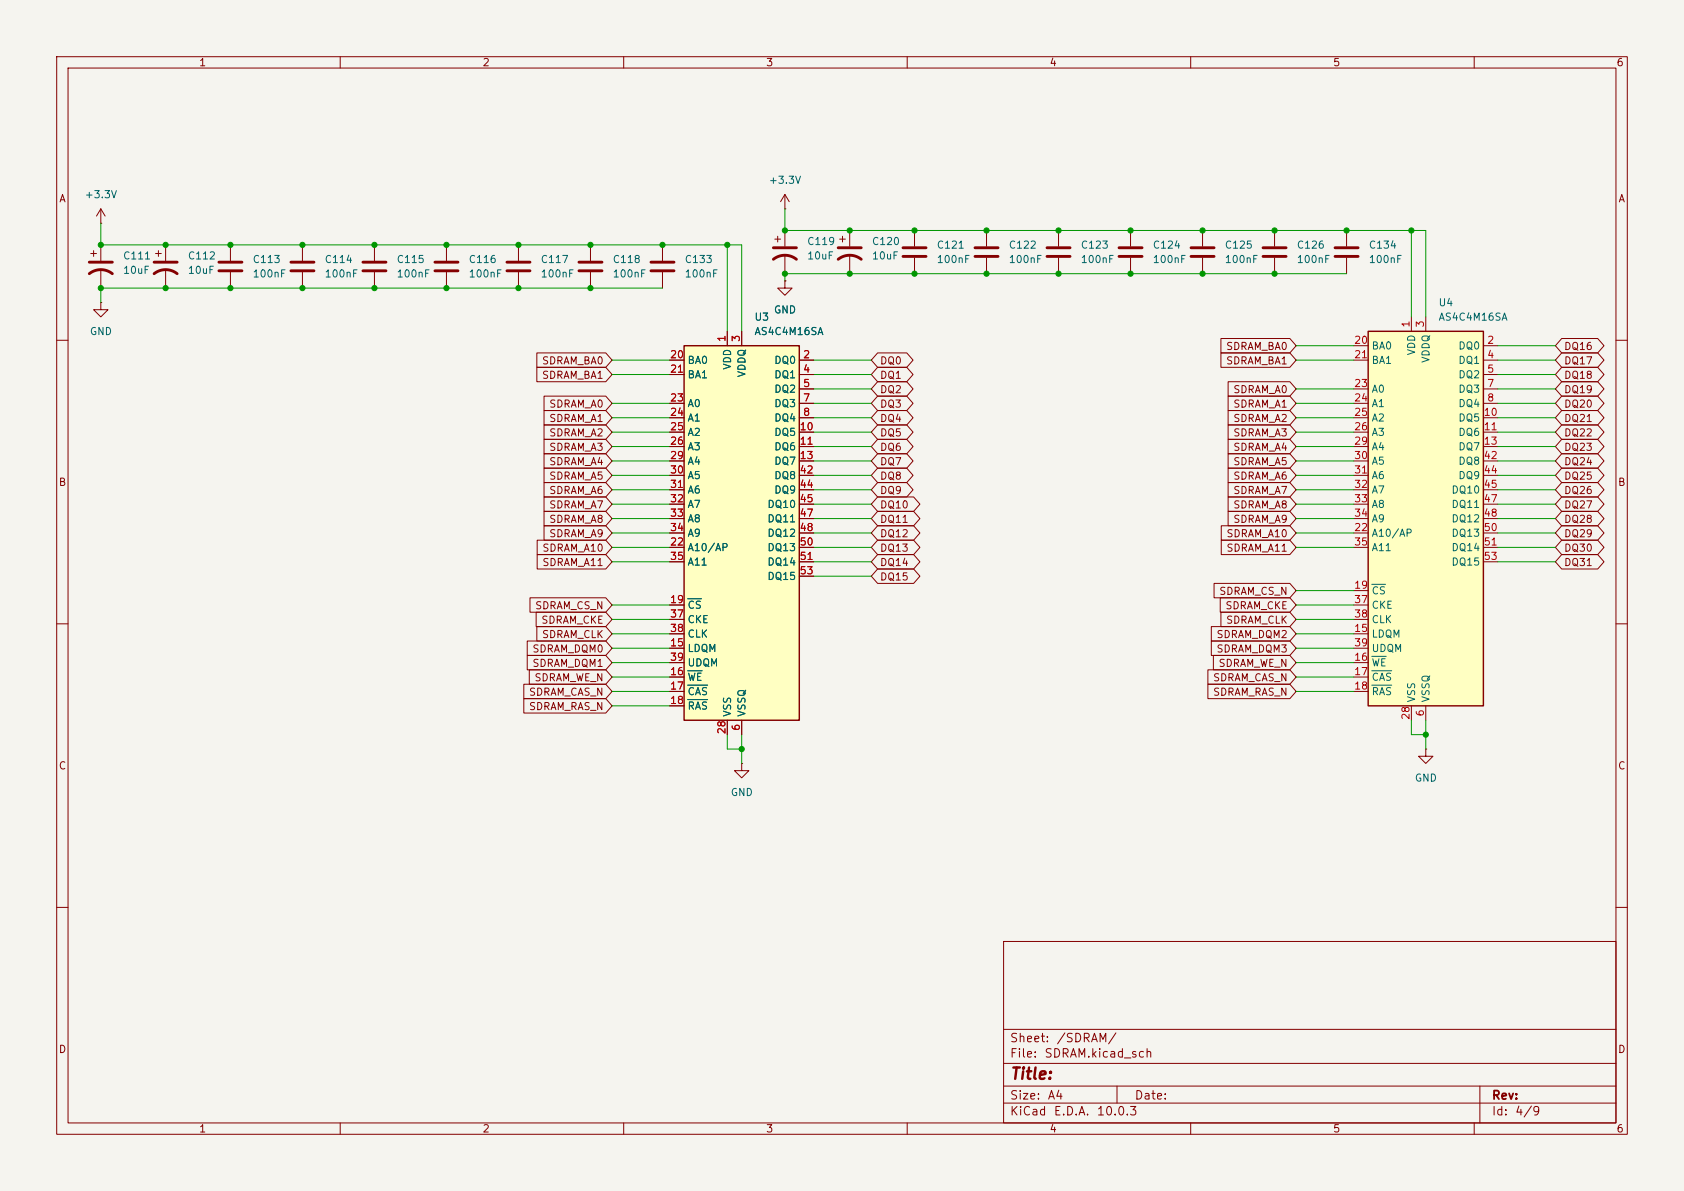
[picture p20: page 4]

LDQM 15 WE 16 CAS 17 RAS 18 CS 19 BA0 20 BA1 21

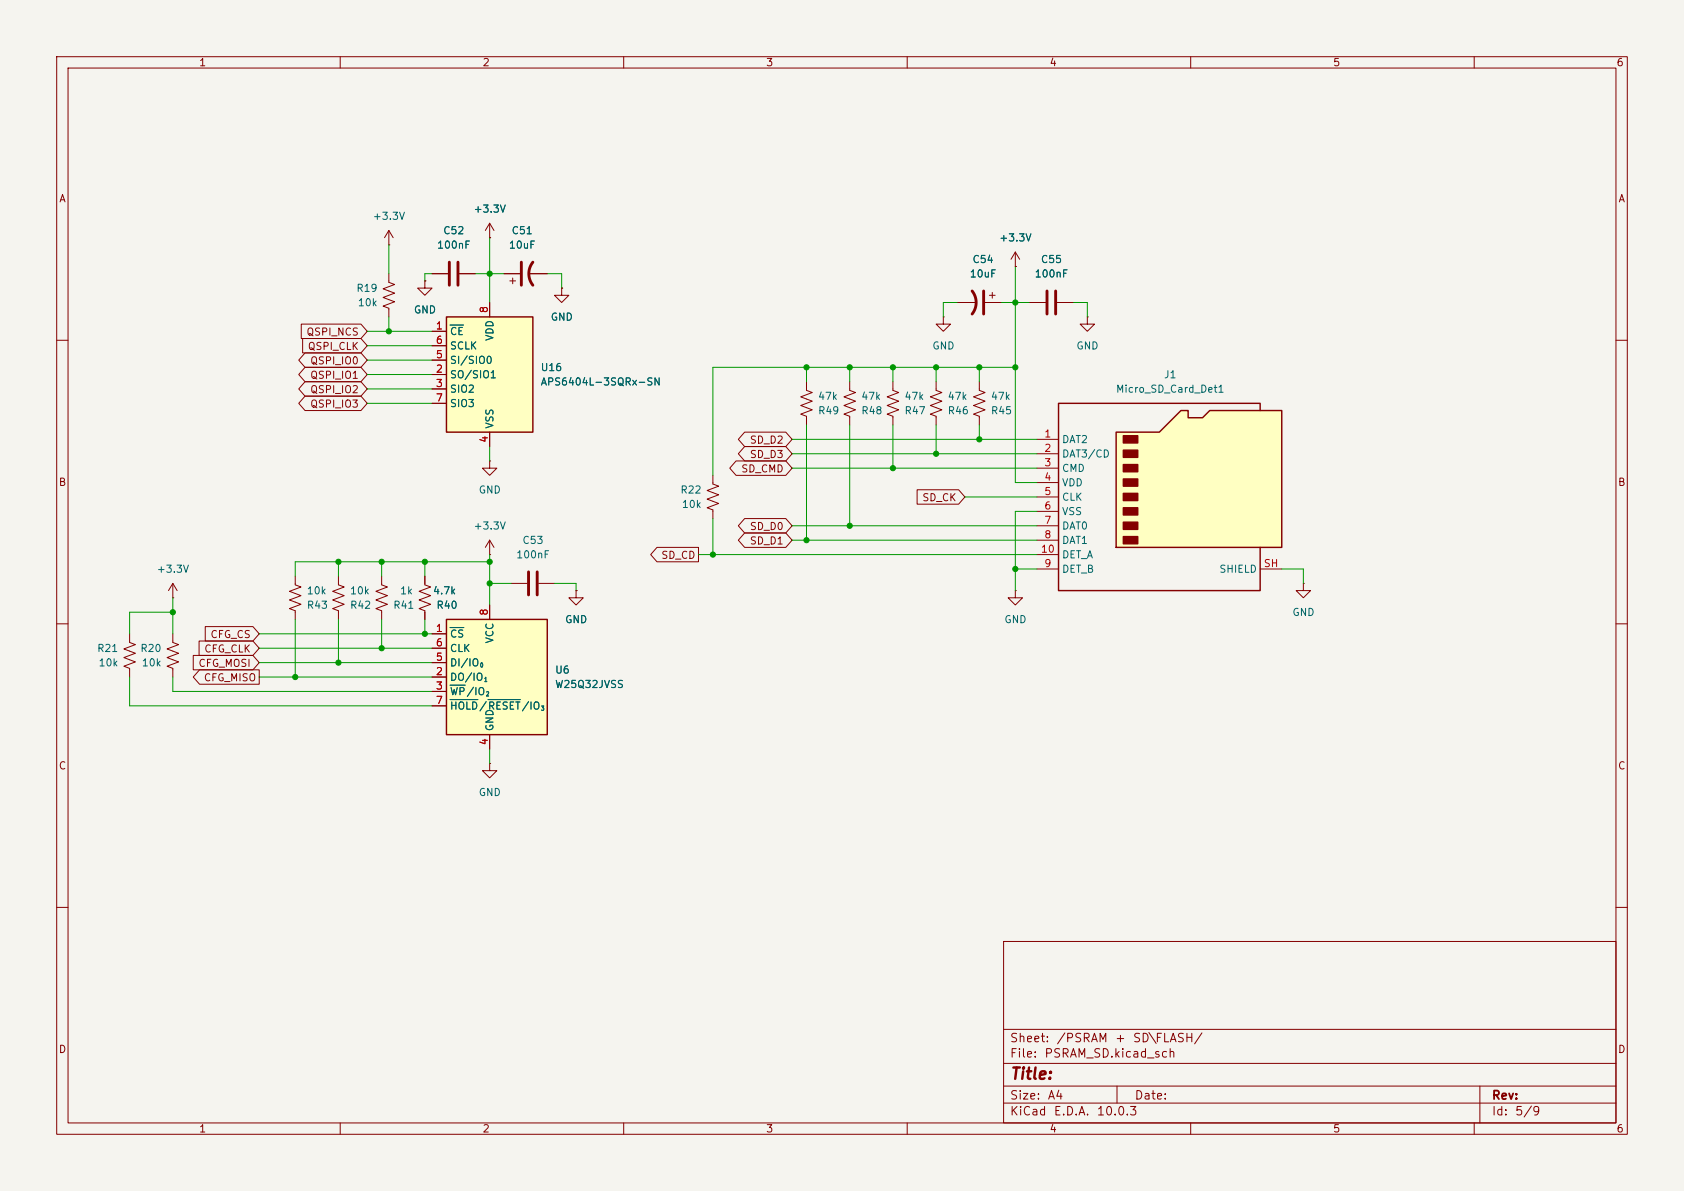
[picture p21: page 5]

4 DI/IO0 5 CLK 6 HOLD/RESET/IO3 7 VCC

Sheet: /PSRAM + SD\FLASH/
File: PSRAM_SD.kicad_sch
Title:

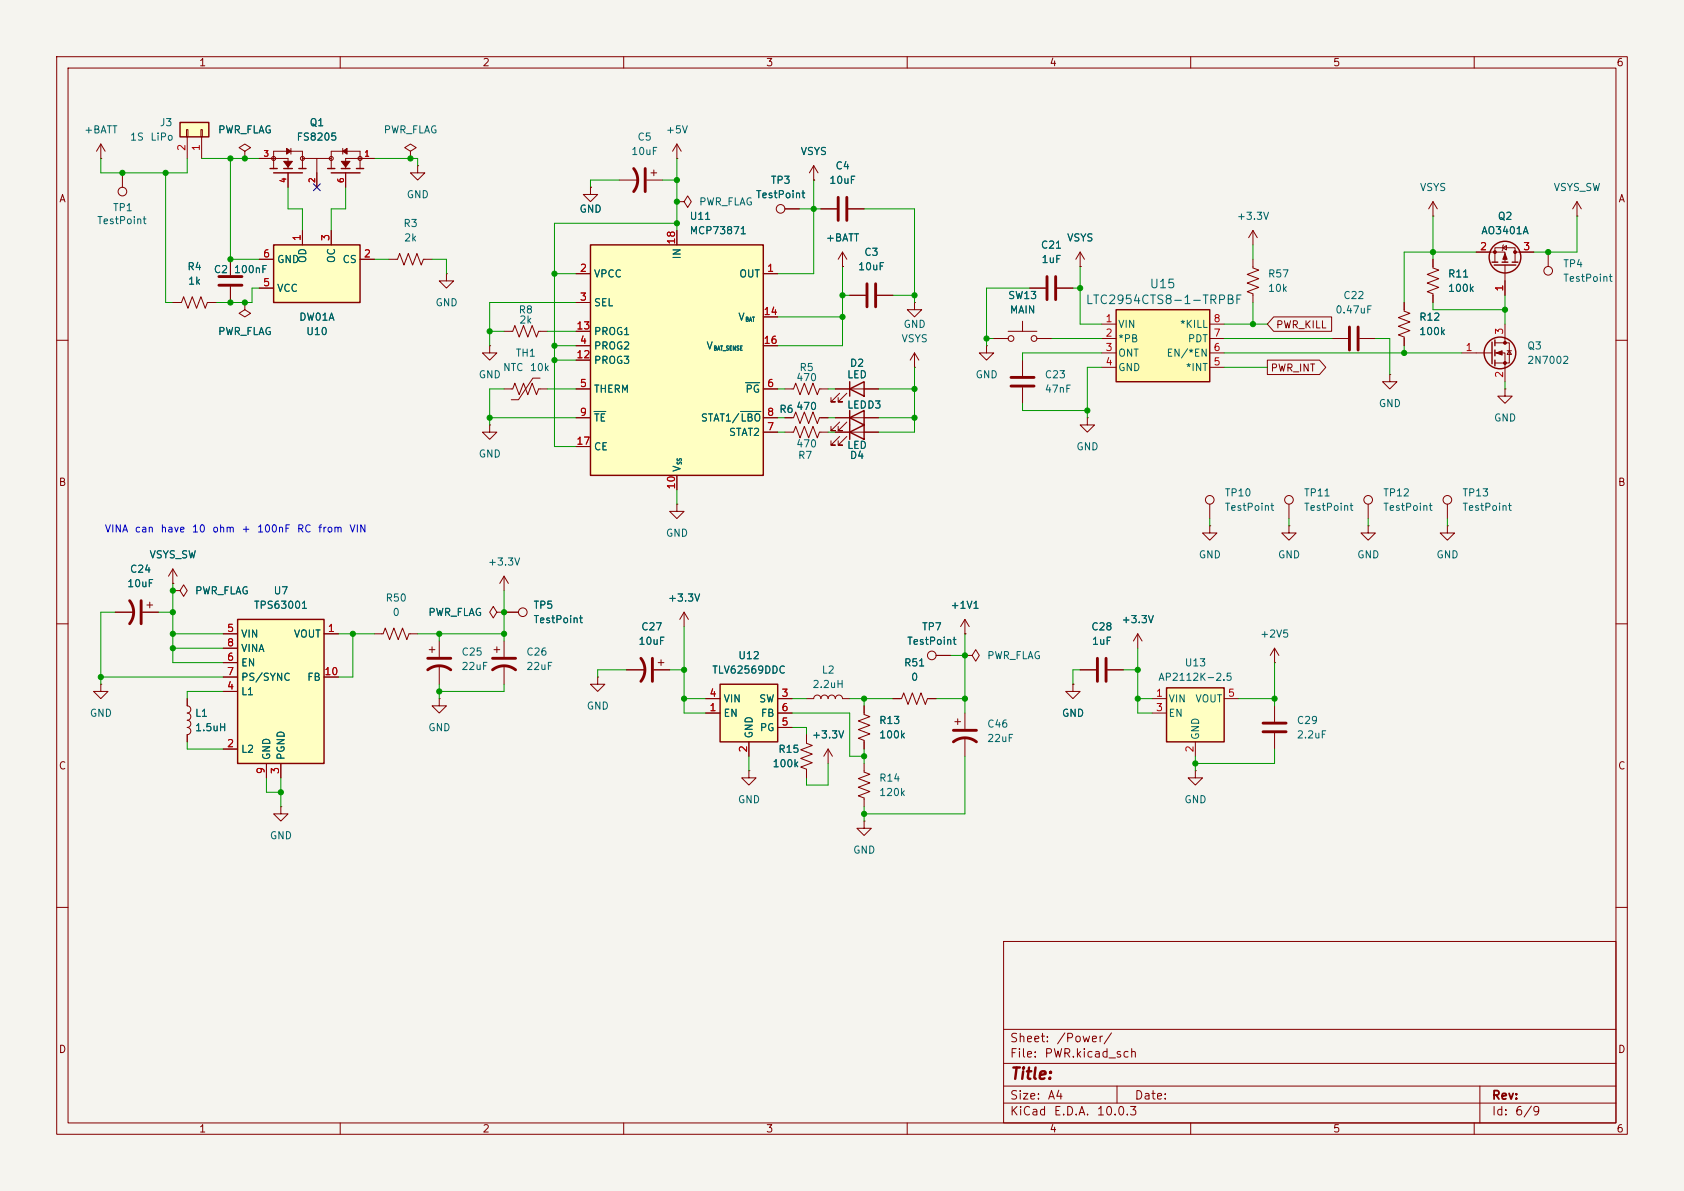
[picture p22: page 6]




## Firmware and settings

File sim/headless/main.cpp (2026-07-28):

// Headless RasterIX (rixif) full-pipeline smoke test.
// GL driver -> command stream -> verilated RTL -> framebuffer -> PPM dumps.
// Wiring mirrors example/qtDebug/qtRasterizerFpga (USE_SIMULATION), minus Qt.

#ifdef USE_POLYSTRESS
#include "PolyStress.hpp"
using Scene = PolyStress;
#elif defined(USE_SPRITE_SCENE)
#include "SpriteScene.hpp"
using Scene = SpriteScene;
#else
#include "Minimal.hpp"
using Scene = Minimal;
#endif
#include "CaptureBusConnector.hpp"
#include "NoThreadRunner.hpp"
#include "RIXGL.hpp"
#include "renderer/devicedatauploader/DeviceDataUploader.hpp"
#include "renderer/threadedvertextransformer/ThreadedVertexTransformer.hpp"
#include <cstdint>
#include <cstdio>

static constexpr uint32_t RESOLUTION_W = 480; // spec target (D1)
static constexpr uint32_t RESOLUTION_H = 272;
static constexpr uint32_t FRAMES = 3; // capture: keep gpu_stream.bin replay short

static uint8_t s_framebuffer[RESOLUTION_W * RESOLUTION_H * 3]; // BGR888 from bus connector

static bool writePpm(const char* path)
{
    FILE* f = fopen(path, "wb");
    if (!f)
        return false;
    fprintf(f, "P6\n%u %u\n255\n", RESOLUTION_W, RESOLUTION_H);
    for (uint32_t i = 0; i < RESOLUTION_W * RESOLUTION_H; i++)
    {
        const uint8_t rgb[3] = { s_framebuffer[i * 3 + 2], s_framebuffer[i * 3 + 1], s_framebuffer[i * 3 + 0] };
        fwrite(rgb, 1, 3, f);
    }
    fclose(f);
    return true;
}

int main()
{
    CaptureBusConnector<> busConnector { s_framebuffer, RESOLUTION_W, RESOLUTION_H }; // tees stream -> gpu_stream.bin
    rr::devicedatauploader::DeviceDataUploader device { busConnector };
    rr::NoThreadRunner workerThread {};
    rr::NoThreadRunner uploadThread {};
    rr::threadedvertextransformer::ThreadedVertexTransformer threadedRasterizer { device, workerThread, uploadThread };

    rr::RIXGL::createInstance(threadedRasterizer);
    rr::RIXGL::getInstance().setRenderResolution(RESOLUTION_W, RESOLUTION_H);

    Scene scene {};
    scene.init(RESOLUTION_W, RESOLUTION_H);

    for (uint32_t frame = 0; frame < FRAMES; frame++)
    {
        uint64_t c0 = rr::VerilatorBusConnector<>::s_simCycles;
        scene.draw();
        rr::RIXGL::getInstance().swapDisplayList();
        uint64_t cyc = rr::VerilatorBusConnector<>::s_simCycles - c0;

        char name[64];
        snprintf(name, sizeof(name), "frame_%02u.ppm", frame);
        if (!writePpm(name))
        {
            fprintf(stderr, "FAIL: cannot write %s\n", name);
            return 1;
        }
        // 60 fps budget at 66.67 MHz = 1,111,167 cycles/frame
        double fps = 66.67e6 / (double)(cyc ? cyc : 1);
        printf("frame %u: %llu sim cycles -> %.1f fps (60fps budget=1.11M) -> %s\n",
               frame, (unsigned long long)cyc, fps, name);
        fflush(stdout);
    }

    rr::RIXGL::getInstance().destroy();
    printf("DONE: %u frames\n", FRAMES);
    return 0;
}

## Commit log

2026-07-28 Initial public release: SS Handheld Console
    Open-source FPGA handheld game console: a hardware 2D tile/sprite PPU + a
    perspective-correct textured 3D rasterizer on a Lattice ECP5, composited to a
    480x272 panel at 60 Hz, driven by an STM32H723. Built with an open toolchain
    (Yosys + nextpnr + Project Trellis).
    Includes the RTL, KiCad hardware, Verilator testbenches, and RTL-rendered
    proof-of-concept frames. 3D core extends RasterIX (GPL-3.0, credited).
    Dual-licensed: rtl/ GPL-3.0-or-later, hardware/ CERN-OHL-P-2.0.
    [Audio.kicad_sch, CPU_CLK.kicad_sch, Comp Board.kicad_sch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]
2026-07-28 Add KiCad 3D board renders
    Top, angled, and bottom raytraced renders of the mainboard (via kicad-cli),
    ein the top README and the hardware README.
2026-07-28 Add schematics PDF and 2D layout export
2026-07-28 Add grouped BOM
    hardware/BOM.csv: 76 line items
    [BOM.csv]
